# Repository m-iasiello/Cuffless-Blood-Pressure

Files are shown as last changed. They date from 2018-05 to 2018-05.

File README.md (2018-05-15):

# Cuffless-Blood-Pressure
Cuffless Blood Pressure monitor using custom PCB developed from AD8232 HRM and Si1143 pulse ox.  Includes several .ino, pcb schems, and solidworks builds.

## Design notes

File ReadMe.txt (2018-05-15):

This folder contains the relevant schematic and files for the Spring 2018 Cuffless Blood Pressure Measurement Project

Contents:

	Powerpoints
		- Tutorial Presentation: Background information and initial project proposal
		- Update Presentations: Updates on progress through the semester
		- Final Presentation: Overall presentation of the project, work, and results

	Schematic and PCB Layout
		- CufflessPTT-v3.sch: The Eagle schematic for the PTT Measurement PCB 
		- CufflessPTT-v3.brd: The Eagle layout for the PTT Measurement PCB

	Software
		- PTT-BP.ino: The main Arduino code file for BP measurement.  
		- QRS_detection.ino: QRS detection algorithm for R wave detection
		- Si1143_pulse_demo.ino: Driver software for the Si1143, as well as helper functions for identification of the PPG signals
		- CUFFLESS.apk: Installer file for the Cuffless Android app.

	Solidworks Files
		- CAD files for the Cuffless case, as well as the locking pin to hold the case together.

Instructions for use:
	
	1. Install the Android app on an Android phone. 
	2. Press the button on the side to turn on the device. The LEDs should come on.
	3. Pair the Android app with the device by opening the app, and then find and pair to the device named HC-06.
	4. Press the start measurement button.
	5. Hold the electrode side of the device against the inside of your wrist. 
	6. Hold one finger of your opposite firmly on the electrdoe on top, and another finger firmly across the LEDs and photodiode.
	7. The device should display measurements as they are acquired.

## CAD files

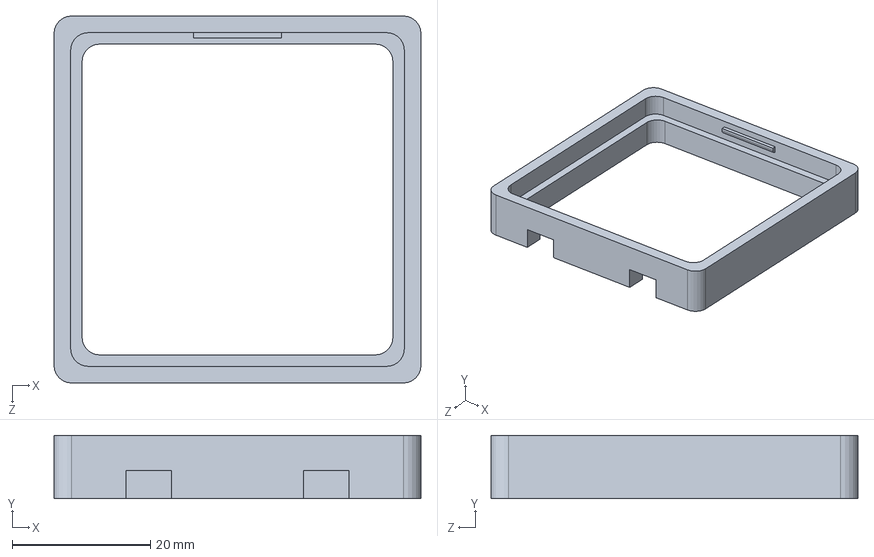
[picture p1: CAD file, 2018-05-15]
Emergency Extender (Uncompleted).SLDPRT
53.1 x 9.14 x 53.1 mm

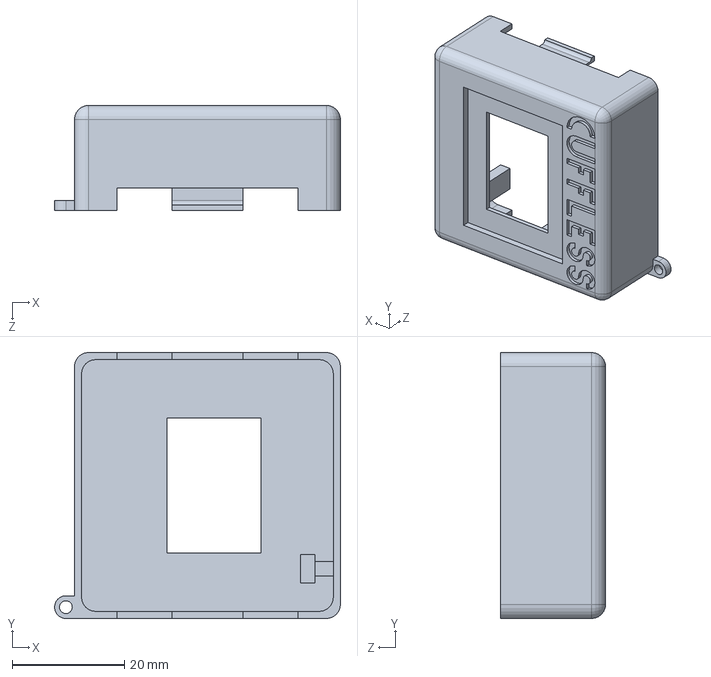
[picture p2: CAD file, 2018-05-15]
Top_V11.SLDPRT
51.1 x 47.5 x 18.8 mm

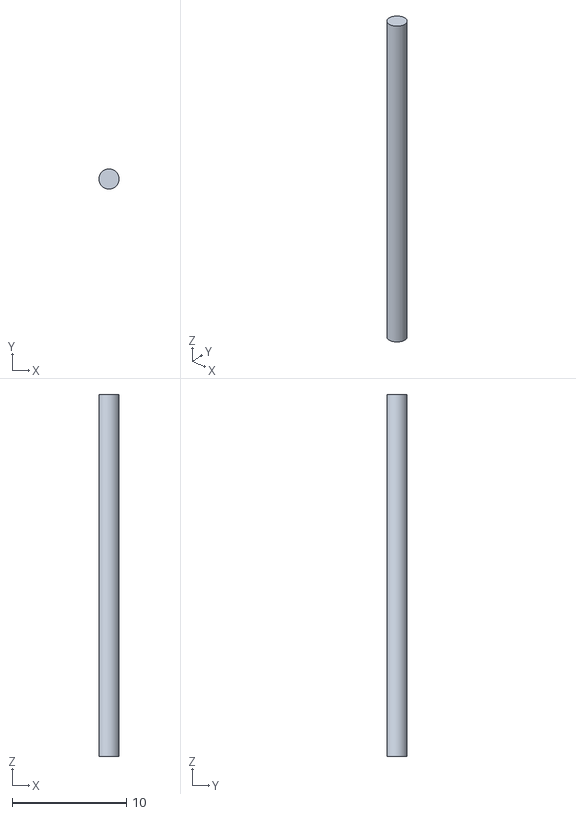
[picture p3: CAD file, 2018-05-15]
Pin.STL
1.78 x 1.78 x 31.8

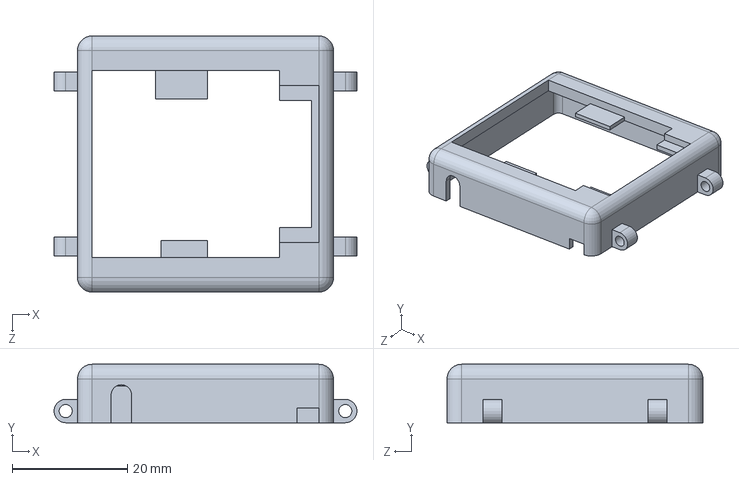
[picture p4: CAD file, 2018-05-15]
Bottom_V8.SLDPRT
52.6 x 10.2 x 44.5 mm

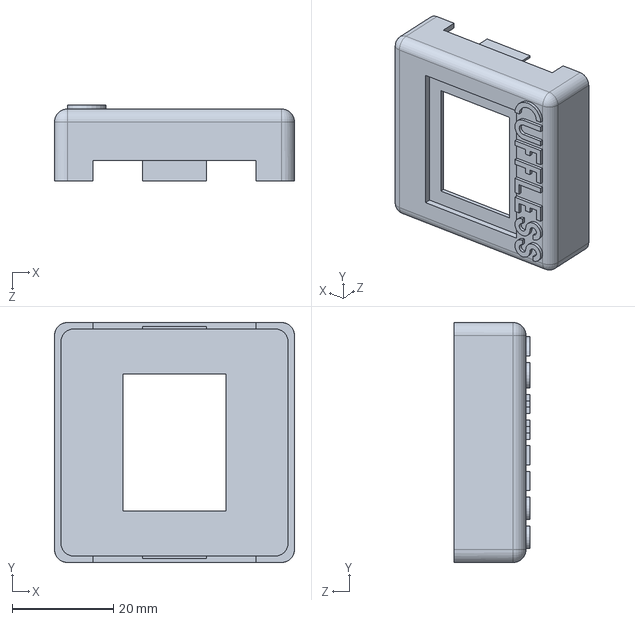
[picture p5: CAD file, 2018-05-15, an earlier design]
Top_V9.SLDPRT
47.5 x 47.5 x 15.0 mm

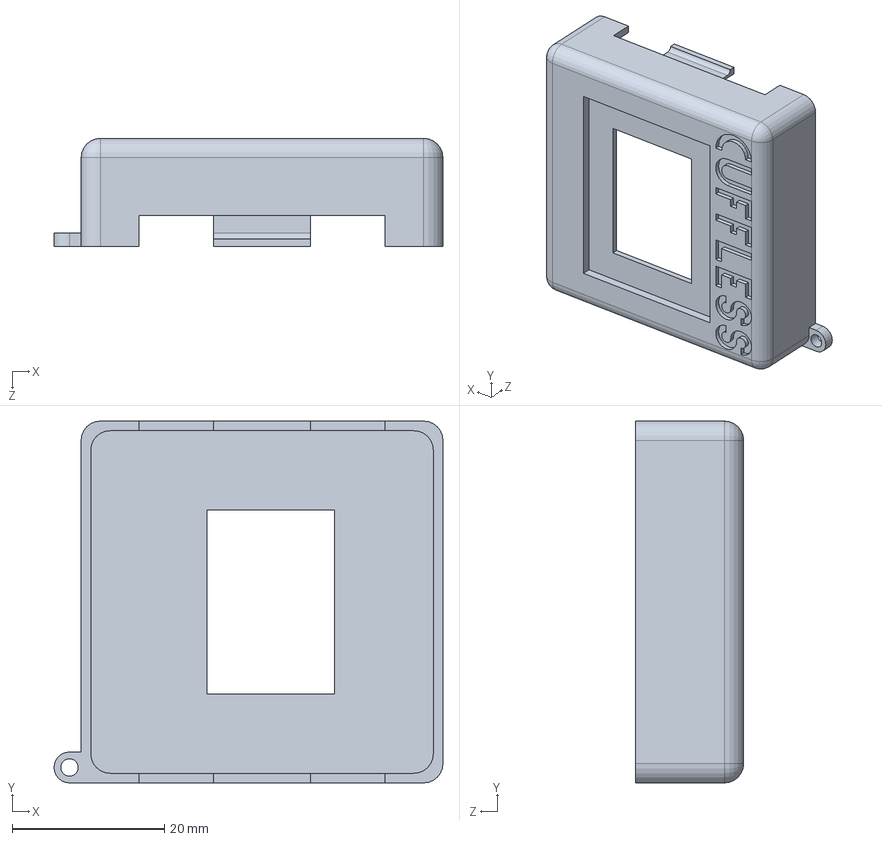
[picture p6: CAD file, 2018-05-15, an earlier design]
Top_V10.SLDPRT
51.1 x 47.5 x 14.2 mm

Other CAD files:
UM2_Top_V11.3mf
Top_V8.SLDPRT
Bottom_V8.STL
Top_V10.STL
Top_V11.STL
Top_V11_Drawing.SLDDRW
Top_V8.STL
Top_V9.STL

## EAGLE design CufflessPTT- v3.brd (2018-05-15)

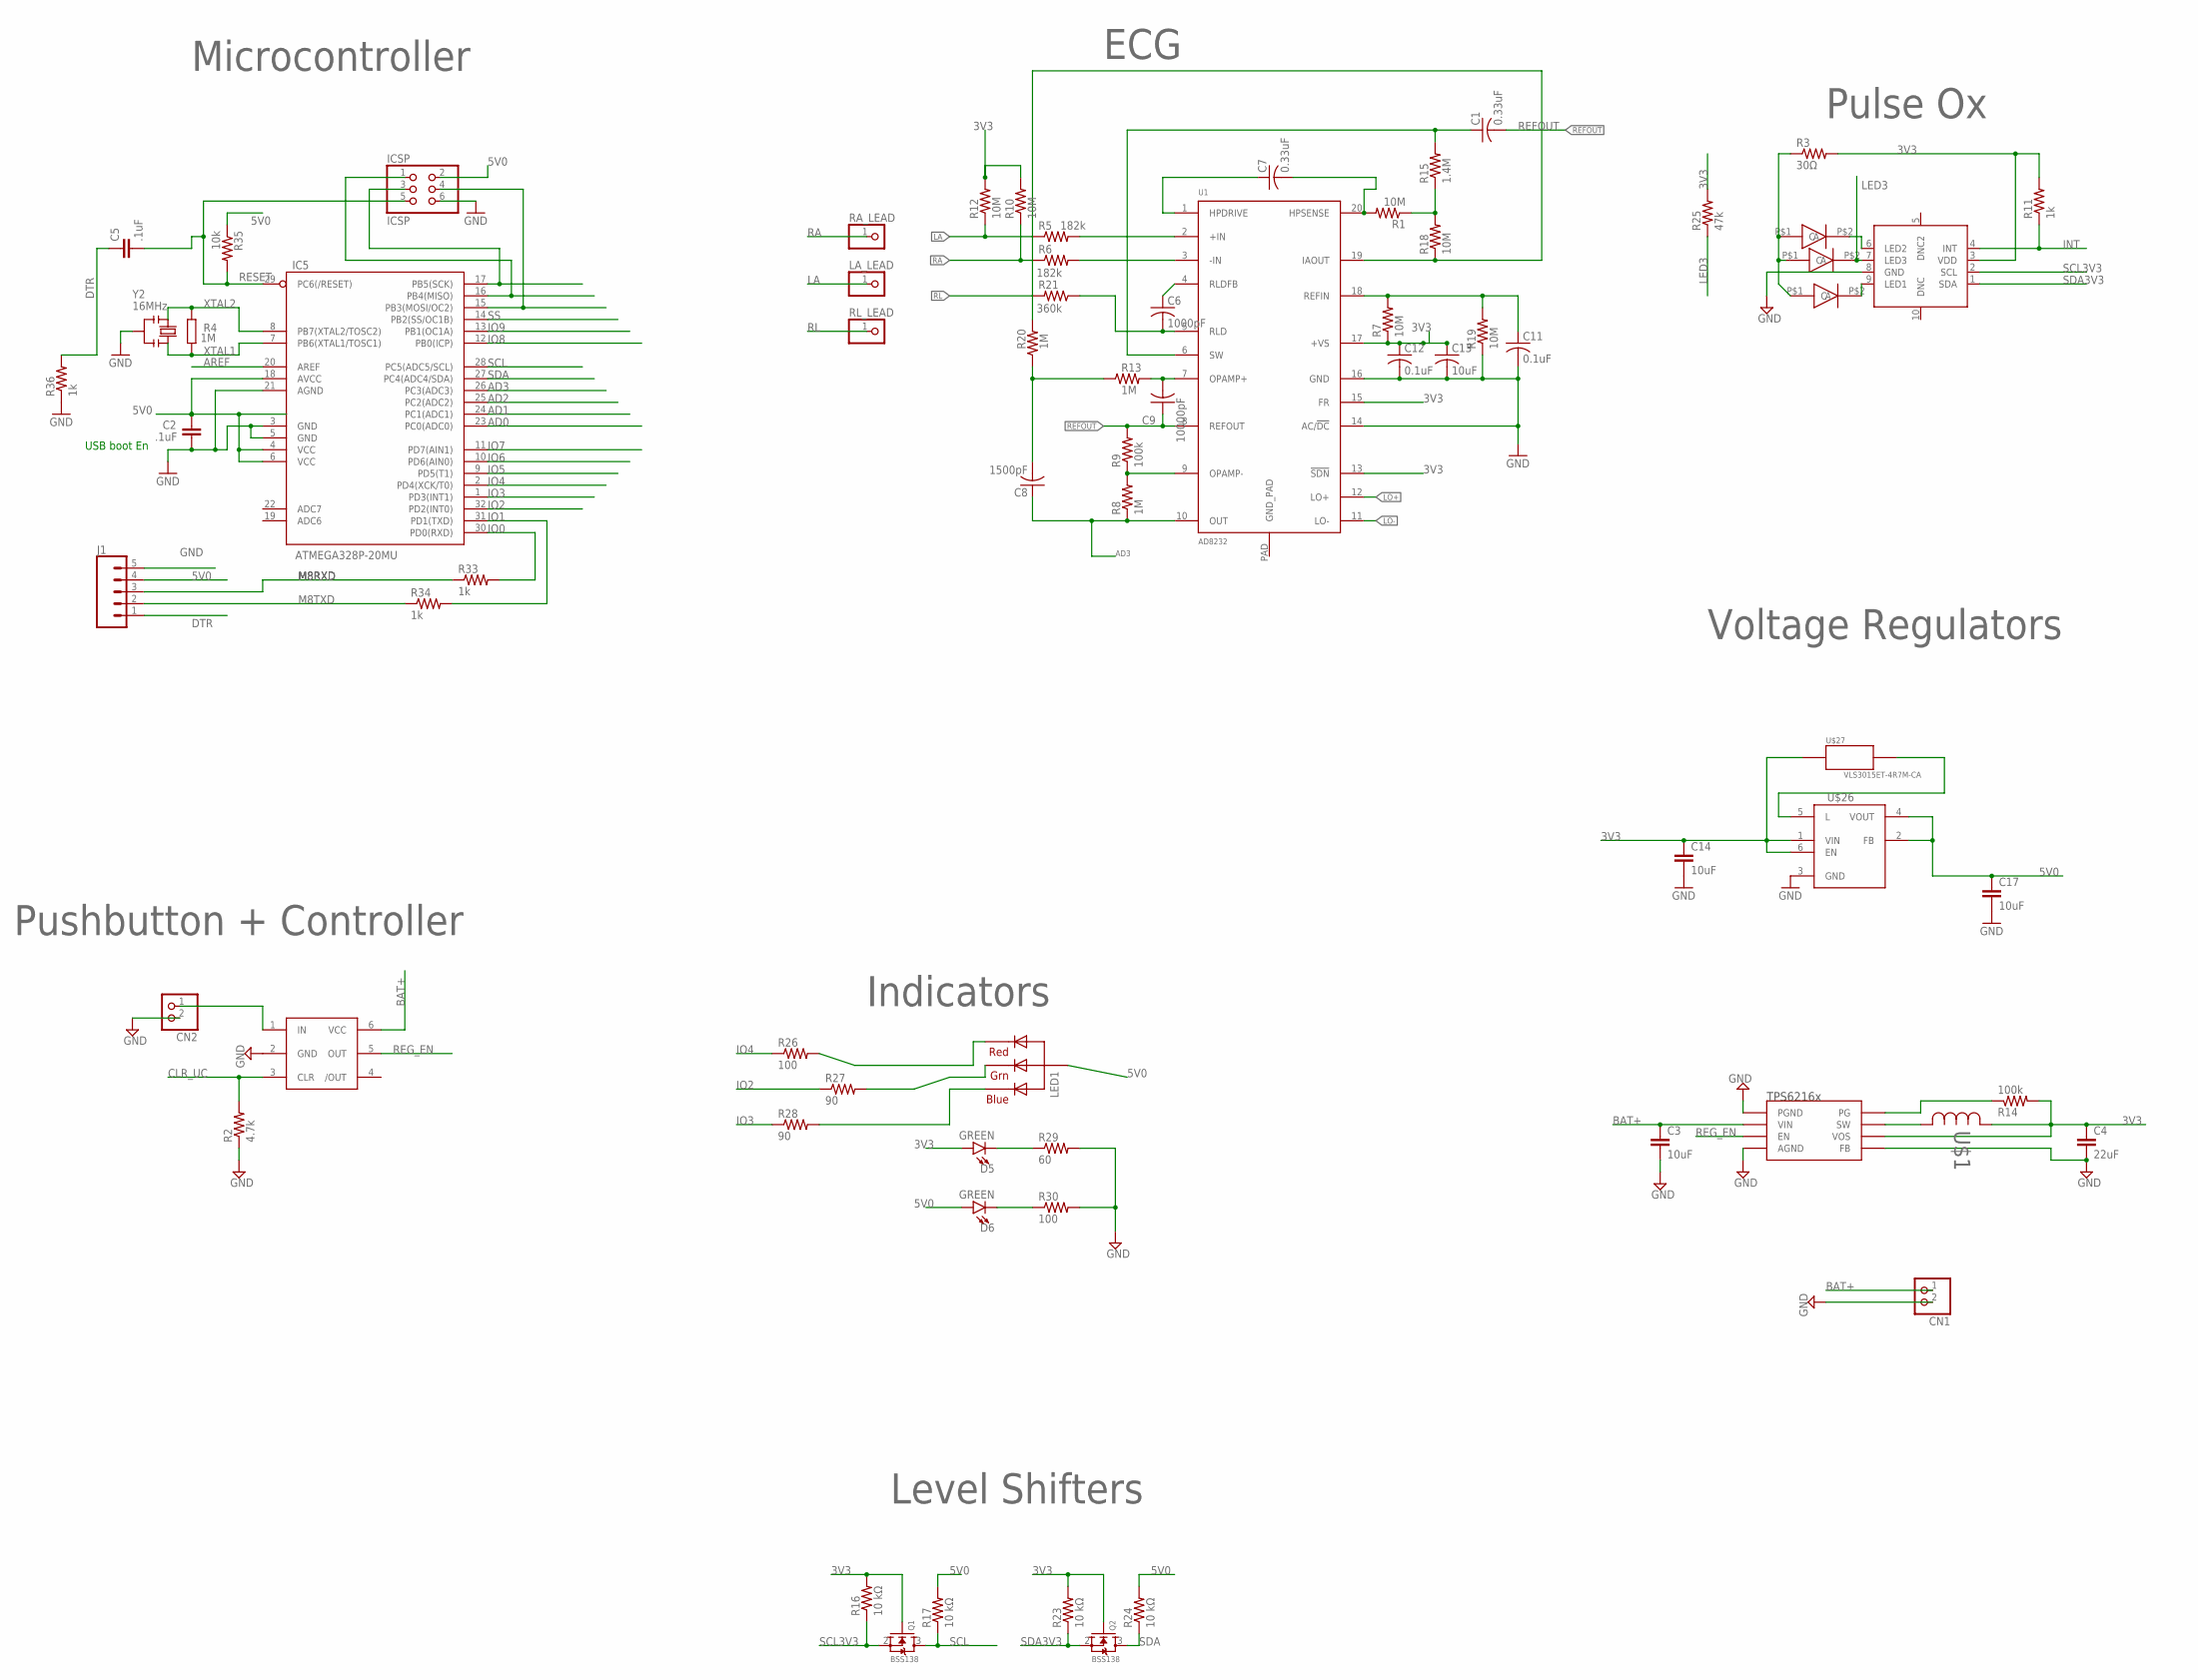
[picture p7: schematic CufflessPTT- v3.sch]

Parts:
C1, C7: 0.33uF; C0603
C2, C5: .1uF; C0603-ROUND
C3, C14, C17: 10uF; C0603; MPN MCNP16V105M5X11
C4: 22uF; C0805
C6: 1000pF; C0603
C8: 1500pF; C0603
C9: 10000pF; C0603
C11, C12: 0.1uF; C0603
C13: 10uF; C0603
CN1, CN2: JST_2PIN-THM; JST-PH-2-THM
D5, D6: GREEN; LED-0603
IC5: ATMEGA328P-20MU; MLF32
ICSP: ICSP; 2X03
J1: CONN_05; 1X05
LA_LEAD: PINHD-1X1; 1X01
LED1: RGBLED_CA-5MM; LED5MMRGB
LED2, LED3, LED4: SMD_COMBO
Q1, Q2: BSS138; SOT23-3
R1, R7, R10, R12, R18, R19: 10M; 0603-RES
R2: 4.7k; R0402
R3: 30Ω; R0402
R4: 1M; R0603-ROUND
R5, R6: 182k; 0603-RES
R8, R13, R20: 1M; 0603-RES
R9: 100k; 0603-RES
R11, R33, R34, R36: 1k; R0402
R14: 100k; R0402
R15: 1.4M; 0603-RES
R16, R17, R23, R24: 10 kΩ; R0402
R21: 360k; 0603-RES
R25: 47k; R0402
R26, R30: 100; R0402
R27, R28: 90; R0402
R29: 60; R0402
R35: 10k; R0402
RA_LEAD: PINHD-1X1; 1X01
RL_LEAD: PINHD-1X1; 1X01
U1: AD8232; LFCSP_20
U$1: VLF3012ST-2R2M1R4; IND_3010
U$4: SI1143; QFN-10
U$5: TPS6216X; 8WSON
U$15: MAX16054; TSOT23-6
U$26: TPS61222; SOT363_6SOIC
U$27: VLS3015ET-4R7M-CA
Y2: 16MHz; RESONATOR

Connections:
3V3: C4.1, C12.1, C13.1, C14.1, D5.A, Q1.1 (G), Q2.1 (G), R3.2, R7.1, R10.2, R11.2, R12.2, R14.2, R16.2, R23.2, R25.2, U1.13 (!SDN), U1.15 (FR), U1.17 (+VS), U$1.1, U$4.3 (VDD), U$5.P$6 (VOS), U$26.1 (VIN), U$26.6 (EN), U$27.1
5V0: C2.2, C17.1, D6.A, IC5.4 (VCC), IC5.6 (VCC), IC5.18 (AVCC), ICSP.2, J1.4, LED1.2 (VCC), R17.2, R24.2, R35.1, U$26.2 (FB), U$26.4 (VOUT)
AD0: IC5.23 (PC0(ADC0))
AD1: IC5.24 (PC1(ADC1))
AD2: IC5.25 (PC2(ADC2))
AD3: C8.1, IC5.26 (PC3(ADC3)), R8.1, U1.10 (OUT)
AREF: IC5.20 (AREF)
BAT+: C3.1, CN1.1 (2), U$5.P$2 (VIN), U$15.6 (VCC)
CLR_UC: R2.2, U$15.3 (CLR)
DTR: C5.1, J1.1, R36.2
GND: C2.1, C3.2, C4.2, C11.2, C12.2, C13.2, C14.2, C17.2, CN1.2 (1), CN2.2 (1), IC5.3 (GND), IC5.5 (GND), IC5.21 (AGND), ICSP.6, J1.5, R2.1, R19.1, R29.2, R30.2, R36.1, U1.14 (AC/!DC), U1.16 (GND), U$4.8 (GND), U$5.P$1 (PGND), U$5.P$4 (AGND), U$5.P$5 (FB), U$5.P$9 (AGND), U$15.2 (GND), U$26.3 (GND), Y2.2
INT: R11.1, U$4.4 (INT)
IO0: IC5.30 (PD0(RXD)), R33.2
IO1: IC5.31 (PD1(TXD)), R34.2
IO2: IC5.32 (PD2(INT0)), R27.1
IO3: IC5.1 (PD3(INT1)), R28.1
IO4: IC5.2 (PD4(XCK/T0)), R26.1
IO5: IC5.9 (PD5(T1))
IO6: IC5.10 (PD6(AIN0))
IO7: IC5.11 (PD7(AIN1))
IO8: IC5.12 (PB0(ICP))
IO9: IC5.13 (PB1(OC1A))
LA: LA_LEAD.1, R5.1, R12.1
LED3: LED2.P$2 (C), R25.1, U$4.7 (LED3)
LO+: U1.12 (LO+)
LO-: U1.11 (LO-)
M8RXD: J1.3, R33.1
M8TXD: J1.2, R34.1
MISO: IC5.16 (PB4(MISO)), ICSP.1
MOSI: IC5.15 (PB3(MOSI/OC2)), ICSP.4
unnamed: R5.2, U1.2 (+IN)
unnamed: CN2.1 (2), U$15.1 (IN)
unnamed: C1.1, R15.2, U1.6 (SW)
unnamed: R1.1, R15.1, R18.2
unnamed: C8.2, R13.1, R20.1
unnamed: R14.1, U$5.P$8 (PG)
unnamed: R6.2, U1.3 (-IN)
unnamed: C9.2, R13.2, U1.7 (OPAMP+)
unnamed: D5.C, R29.1
unnamed: C7.2, R1.2, U1.20 (HPSENSE)
unnamed: C11.1, R7.2, R19.2, U1.18 (REFIN)
unnamed: U$1.2, U$5.P$7 (SW)
unnamed: R8.2, R9.1, U1.9 (OPAMP-)
unnamed: C7.1, U1.1 (HPDRIVE)
unnamed: C6.1, U1.4 (RLDFB)
unnamed: D6.C, R30.1
unnamed: R18.1, R20.2, U1.19 (IAOUT)
unnamed: C6.2, R21.1, U1.5 (RLD)
unnamed: LED2.P$1 (A), LED3.P$1 (A), LED4.P$1 (A), R3.1
unnamed: U$26.5 (L), U$27.2
unnamed: LED3.P$2 (C), U$4.6 (LED2)
unnamed: LED1.4 (BLUE), R28.2
unnamed: LED1.3 (GREEN), R27.2
unnamed: LED1.1 (RED), R26.2
unnamed: LED4.P$2 (C), U$4.9 (LED1)
RA: R6.1, R10.1, RA_LEAD.1
REFOUT: C1.2, C9.1, R9.2, U1.8 (REFOUT)
REG_EN: U$5.P$3 (EN), U$15.5 (OUT)
RESET: C5.2, IC5.29 (PC6(/RESET)), ICSP.5, R35.2
RL: R21.2, RL_LEAD.1
SCK: IC5.17 (PB5(SCK)), ICSP.3
SCL: IC5.28 (PC5(ADC5/SCL)), Q1.3 (D), R17.1
SCL3V3: Q1.2 (S), R16.1, U$4.2 (SCL)
SDA: IC5.27 (PC4(ADC4/SDA)), Q2.3 (D), R24.1
SDA3V3: Q2.2 (S), R23.1, U$4.1 (SDA)
SS: IC5.14 (PB2(SS/OC1B))
XTAL1: IC5.7 (PB6(XTAL1/TOSC1)), R4.1, Y2.3
XTAL2: IC5.8 (PB7(XTAL2/TOSC2)), R4.2, Y2.1

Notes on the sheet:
Voltage Regulators
Pulse Ox
Pushbutton + Controller
ECG
USB boot En
Indicators
Microcontroller
Level Shifters

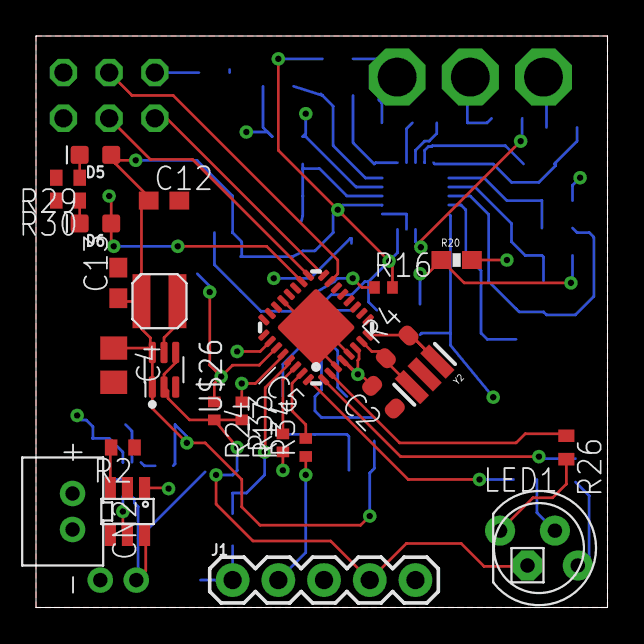
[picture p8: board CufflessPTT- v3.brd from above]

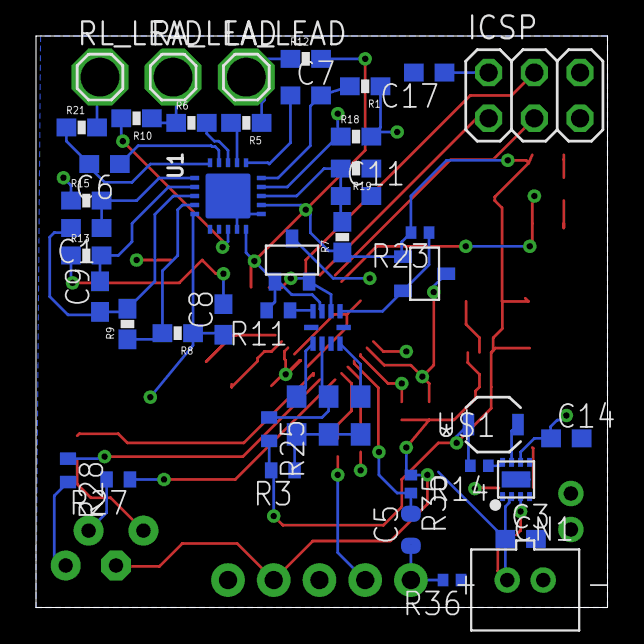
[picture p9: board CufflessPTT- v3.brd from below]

Board: 4 copper layers, 31.8 x 31.8 mm, 71 parts (46 on the bottom side), 56 nets.

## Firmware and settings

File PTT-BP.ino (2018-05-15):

// PTT calculation program using Sparkfun AD8232 HRM and SI1143 PPG sensor.  BME 525
// Includes:
/* SI114_Pulse_Demo.ino
 * demo code for the Modern Device SI1143-based pulse sensor
 * http://moderndevice.com/product/pulse-heartbeat-sensor-pulse-sensor-1x/
 * Paul Badger 2013 with plenty of coding help from Jean-Claude Wippler
 * Hardware setup - please read the chart below and set the appropriate options
 */
// Michael Iasiello

#include <stdio.h>
#include <stdlib.h>
#include <SI114.h> 
const int SAMPLES_TO_AVERAGE = 5;             // samples for smoothing 1 to 10 seem useful 5 is default
// increase for smoother waveform (with less resolution - slower!) 


 //#define SEND_TOTAL_TO_PROCESSING   // Use this option exclusive of other options
                                      // for sending data to HeartbeatGraph in Processing
// #define POWERLINE_SAMPLING         // samples on an integral of a power line period [eg 1/60 sec]
// #define AMBIENT_LIGHT_SAMPLING     // also samples ambient slight (slightly slower)
// #define PRINT_LED_VALS             // print LED raw values
 #define GET_PULSE_READING          // prints HB and signal size


int binOut;     // 1 or 0 depending on state of heartbeat
int BPM;
unsigned long red;        // read value from visible red LED
unsigned long IR1;        // read value from infrared LED1
unsigned long IR2;       // read value from infrared LED2
unsigned long total;     // all three LED reads added together
int signalSize;          // the heartbeat signal minus the offset
const int portForSI114 = 0;
PortI2C myBus (portForSI114);
PulsePlug pulse (myBus); 





// variables for lowpass (moving average) filter
int sensorValue;
float EMA_a_l = 0.4;      //initialization of EMA alpha
float lowpass = 0;          //initialization of EMA S

//variables for highpass (Exp moving average) filter
float EMA_a = 0.026177; //alpha for EMA eq., cuttoff = 3Hz
float EMA_s = 0;            //initialize EMA s
float highpass = 0;
float sensorVal = 0.0;

float threshold = 90;  

//variables for peak detection
float next_ecg_pt = 0;
float ECG_bpm = 0;
float prev_ecg_pt = 0;
float ECG_time_buff = 0;
unsigned long ECG_max_time;
//static unsigned long lastPeakTime;
boolean QRS_detected = false;
boolean get_ready = false;
unsigned long R_peak = 0;


const int LED_PIN =   13;      // the number of the LED pin (digital)

const int ECG_PIN =   A3;       // the number of the ECG pin (analog)
const int PWM_PIN =   1;       // the number of the PWM pin (analog)

const int GREEN = 2;
const int BLUE = 4;
const int RED = 3;

// timing variables
unsigned long foundTimeMillis = 0;        // time at which last QRS was found
unsigned long old_foundTimeMillis = 0;        // time at which QRS before last was found


// PTT and BP variables
int i =0;
int j=0;
int k =0;
float PTT_avg=0;
float PTT_sum = 0;
float lastBP = 0;
float bpm_ecg;
float BP_total =0;
float BP_avg=0;
float BP_val=0;
int counter=0;
unsigned long ECG_peak_time;
static unsigned long PPG_peak_time;
boolean check_ppg = false;
int PTT_val;
float bpm = 0;
float lastBP_val = 0;

// Variable timers
unsigned long currentTime = 0;
unsigned long lastTime = 0;
unsigned long lastOutputTime;

int incomingByte = 0;

void setup() {
  // initialize the serial communication:

    if (pulse.isPresent()) {
        Serial.print("PPG Sensor Found");
        Serial.println(portForSI114);
    }
        else{
        Serial.print("PPG Sensor not found.");
        Serial.println(portForSI114);
    }
    Serial.begin(9600);
    
    Serial.println("\n Welcome To to the Cuffless BP Monitor!");
    Serial.println("Place device on inside of wrist. Place opposite fingers on top electrode and LEDs");
    
    digitalWrite(3, HIGH);

      // set the digital pin as output:
  pinMode(LED_PIN, OUTPUT);
  pinMode(7, OUTPUT);
  pinMode(ECG_PIN, INPUT);

  pinMode(GREEN, OUTPUT);
  pinMode(BLUE, OUTPUT);
  pinMode(RED, OUTPUT);


  // set LED to off
  digitalWrite(LED_PIN, LOW);

  //Setting LEDS init
  digitalWrite(GREEN, LOW);
  digitalWrite(BLUE, LOW);
  digitalWrite(RED, HIGH);

  initPulseSensor();


}
  
void loop() {
  
      currentTime = millis();

      // Tell user what is happening based on elapsed time
      if((currentTime - lastTime)>=5000){
        Serial.println(" ...Measurement in progress... ");
        lastTime = currentTime;
        
        if((currentTime - lastOutputTime)>=10000){
          Serial.println(" ...Reposition the device... "); 
        }
      } 


      // Reset microcontroller if LEDs bugged
      // Send '\n" or just enter through serial monitor input (or smartphone app)
      if (Serial.available()>0){
        incomingByte = Serial.read();
        if(incomingByte == 10){
          softReset();
        }
        Serial.println(incomingByte, DEC);
      }

      // Read values for both ECG and PPG
      // ECG value will need to be filtered
      readPulseSensor();        
      sensorValue = analogRead(A3);                

      // **ECG LOWPASS EMA**
      lowpass = (EMA_a_l*sensorValue) + ((1-EMA_a_l)*lowpass);    //run the EMA
           
      // **ECG HIGHPASS EMA**
      EMA_s = (EMA_a*lowpass) + ((1-EMA_a)*EMA_s);
      highpass = lowpass - EMA_s;
      //Serial.println(highpass);


      
      //QRS detection using thresholding
      next_ecg_pt = highpass;

      // Check to see if the next ECG point is greater than a predetermined threshold
      // If it is, mark the time & set a flag
      // If it is not, do not set flag
      if(next_ecg_pt > threshold){
        ECG_max_time = millis();   
        get_ready = true;
      }
      else if(next_ecg_pt <= threshold){
        get_ready = false;
      }

      // If the flag is set, check to see if the ECG is decreasing.
      // This signifies that the R-peak has just occured
      // If true: set another flag, flash LED yellow
      // If false: reset flag, flash red LED
      if(get_ready == true){
          if(next_ecg_pt < prev_ecg_pt){
            get_ready = false;
            foundTimeMillis = ECG_max_time;
            QRS_detected = true;

            //Set Yellow LED ON
              digitalWrite(GREEN, HIGH);
              digitalWrite(BLUE, LOW);
              digitalWrite(RED, HIGH);
          }
          else{
            get_ready = false;
            
            //Set Red LED ON
            digitalWrite(GREEN, LOW);
            digitalWrite(BLUE, LOW);
            digitalWrite(RED, HIGH);

          }
        }

      prev_ecg_pt = next_ecg_pt;

      // Check to see if the QRS detection has occured on succesive heartbeats
      // This is important for calculating HR.
      // If true: set new flags, calculate HR, store QRS time, flash LED blue
      // IF false: reset flags
      if (QRS_detected == true && (foundTimeMillis - old_foundTimeMillis)< 2000 && (foundTimeMillis - old_foundTimeMillis)> 700){
        
        QRS_detected = false;
        ECG_bpm = 60000/(foundTimeMillis - old_foundTimeMillis);
        
        ECG_peak_time = old_foundTimeMillis;
        check_ppg = true;

        //Set Blue LED ON
        digitalWrite(GREEN, LOW);
        digitalWrite(BLUE, HIGH);
        digitalWrite(RED, LOW);

        Serial.println("ECG signal acquired.");
      }
      else{
        QRS_detected = false;
        check_ppg = false;
      }
      old_foundTimeMillis = foundTimeMillis;

      
      // If the flag is set, we need to check the PTT value and see if it is in an appropriate ra
      if(check_ppg == true){
          check_ppg = false;
          PTT_val = PPG_peak_time - ECG_peak_time;

          // Set green LED ON
          digitalWrite(GREEN, LOW);
          digitalWrite(BLUE, HIGH);
          digitalWrite(RED, LOW);
          
         if(PTT_val < 600 && PTT_val>25){
              //Serial.print(PTT_val);
              //Serial.print();
              if(PTT_val>500){
                PTT_val = PTT_val/6;
              }
              else if(PTT_val>400){
                PTT_val = PTT_val/5;
              }
              else if(PTT_val>300){
                PTT_val = PTT_val/4;
              }
              else if(PTT_val>200){
                  PTT_val = PTT_val/3;
              }
              else if(PTT_val<50){
                PTT_val=PTT_val*4;
              }
              else if(PTT_val<20){
                PTT_val=PTT_val*5;
              }
              
              
              
              //Serial.print(PTT_val);


              bpm = (ECG_bpm + BPM)/2;
              
              lastBP_val = BP_val;
              BP_val = (-0.6881*PTT_val) + 210.94; 
              BP_val = BP_val*0.85;
              BP_total = BP_avg*counter + BP_val;
              counter++;
              BP_avg = BP_total/counter;
              
              Serial.print("BP measurement found (");
              Serial.print(counter);
              Serial.print("/5): ");
              Serial.println(BP_avg);
              //Serial.print("Your HR is"); 
              //Serial.print(" ");
             // Serial.print(ECG_bpm);
              //Serial.print(" beats per minute. ");

              // Start counting in between output times
              // If the time is greater than some threshold,
              // instruct the user to reposition finger
              lastOutputTime = currentTime;

             if(counter ==5){
                //Set Purple LED ON
                digitalWrite(GREEN, HIGH);
                digitalWrite(BLUE, LOW);
                digitalWrite(RED, LOW);

                //leave green light on for 1 second
                delay(1000);
                

                Serial.println("BP measurement found (5/5).");

                Serial.println("Your Systolic BP is estimated to be ");
                Serial.print(BP_avg);
                Serial.print(" mmHg. ");
                Serial.println("Continue to measure again. ");

                
                counter = 0;
                BP_avg = 0;
                BP_total - 0;
              }        
          }
          else{
              check_ppg = false;
              QRS_detected = false;
              get_ready = false;     
          }
      }
      
}
      

// simple smoothing function for  heartbeat detection and processing
float smooth(float data, float filterVal, float smoothedVal){

    if (filterVal > 1){      // check to make sure param's are within range
        filterVal = .99;
    }
    else if (filterVal <= 0.0){
        filterVal = 0.01;
    }

    smoothedVal = (data * (1.0 - filterVal)) + (smoothedVal  *  filterVal);
    return smoothedVal;
    
}

void softReset(){
  asm volatile (" jmp 0");
}

void initPulseSensor(){
    
    pulse.setReg(PulsePlug::HW_KEY, 0x17);  
    // pulse.setReg(PulsePlug::COMMAND, PulsePlug::RESET_Cmd);

   
    pulse.setReg(PulsePlug::INT_CFG, 0x03);       // turn on interrupts
    pulse.setReg(PulsePlug::IRQ_ENABLE, 0x10);    // turn on interrupt on PS3
    pulse.setReg(PulsePlug::IRQ_MODE2, 0x01);     // interrupt on ps3 measurement
    pulse.setReg(PulsePlug::MEAS_RATE, 0x84);     // see datasheet
    pulse.setReg(PulsePlug::ALS_RATE, 0x08);      // see datasheet
    pulse.setReg(PulsePlug::PS_RATE, 0x08);       // see datasheet

    // Current setting for LEDs pulsed while taking readings
    // PS_LED21  Setting for LEDs 1 & 2. LED 2 is high nibble
    // each LED has 16 possible (0-F in hex) possible settings
    // read the 
    pulse.setReg(PulsePlug::PS_LED21, 0xFF);      // LED current for 2 (IR1 - high nibble) & LEDs 1 (red - low nibble) 
    pulse.setReg(PulsePlug::PS_LED3, 0x0F);       // LED current for LED 3 (IR2)

   

    pulse.writeParam(PulsePlug::PARAM_CH_LIST, 0x77);         // all measurements on

    // increasing PARAM_PS_ADC_GAIN will increase the LED on time and ADC window
    // you will see increase in brightness of visible LED's, ADC output, & noise 
    // datasheet warns not to go beyond 4 because chip or LEDs may be damaged
    pulse.writeParam(PulsePlug::PARAM_PS_ADC_GAIN, 0x04);


    // You can select which LEDs are energized for each reading.
    // The settings below turn on only the LED that "normally" would be read
    // ie LED1 is pulsed and read first, then LED2 is pulsed and read etc.
    pulse.writeParam(PulsePlug::PARAM_PSLED12_SELECT, 0x21);  // 21 = LED 2 & LED 1 (red) resp.                                                              
    pulse.writeParam(PulsePlug::PARAM_PSLED3_SELECT, 0x04);   // 4 = LED 3 only

    // Sensors for reading the three LEDs
    // 0x03: Large IR Photodiode
    // 0x02: Visible Photodiode - cannot be read with LEDs on - just for ambient measurement
    // 0x00: Small IR Photodiode
    pulse.writeParam(PulsePlug::PARAM_PS1_ADCMUX, 0x02);      // PS1 photodiode select 
    pulse.writeParam(PulsePlug::PARAM_PS2_ADCMUX, 0x02);      // PS2 photodiode select 
    pulse.writeParam(PulsePlug::PARAM_PS3_ADCMUX, 0x02);      // PS3 photodiode select  

    pulse.writeParam(PulsePlug::PARAM_PS_ADC_COUNTER, B01110000);    // B01110000 is default                                   
    pulse.setReg(PulsePlug::COMMAND, PulsePlug::PSALS_AUTO_Cmd);     // starts an autonomous read loop
    // Serial.println(pulse.getReg(PulsePlug::CHIP_STAT), HEX);  
}

void readPulseSensor(){

    static int foundNewFinger;
    static  int valley=0, peak=0, smoothPeak, smoothValley, binOut, lastBinOut, BPM;
    static unsigned long lastTotal, lastMillis,  valleyTime = millis(), lastValleyTime = millis(), peakTime = millis(), lastPeakTime=millis(), lastBeat, beat;
    static float baseline, HFoutput, HFoutput2, shiftedOutput, LFoutput, hysterisis;
    

    
    unsigned long total=0, start;
    int i=0;
    int signalSize;
    red = 0;
    IR1 = 0;
    IR2 = 0;
    total = 0;
    start = millis();
         
    
     #ifdef POWERLINE_SAMPLING
     
     while (millis() - start < 16){   // 60 hz - or use 33 for two cycles
     // 50 hz in Europe use 20, or 40
       Serial.print("sample");
     #else     
     while (i < SAMPLES_TO_AVERAGE){      
     #endif
     
     
     #ifdef AMBIENT_LIGHT_SAMPLING   
     pulse.fetchData();
     
     #else 
     pulse.fetchLedData();
     #endif
     
     red += pulse.ps1;
     IR1 += pulse.ps2;
     IR2 += pulse.ps3;
     i++;
     }
     
    red = red / i;  // get averages
    IR1 = IR1 / i;
    IR2 = IR2 / i;
    total = red + IR1 + IR2;
    
   

//#ifdef AMBIENT_LIGHT_SAMPLING
//
//    Serial.print(pulse.resp, HEX);     // resp
//    Serial.print("\t");
//    Serial.print(pulse.als_vis);       //  ambient visible
//    Serial.print("\t");
//    Serial.print(pulse.als_ir);        //  ambient IR
//    Serial.print("\t");
//
//#endif

//
//#ifdef PRINT_LED_VALS
//
//    Serial.print(red);
//    Serial.print("\t");
//    Serial.print(IR1);
//    Serial.print("\t");
//    Serial.print(IR2);
//    Serial.print("\t");
//    Serial.println((long)total);   
//
//#endif

 #ifdef SEND_TOTAL_TO_PROCESSING
    //Serial.println(total);
 #endif

 #ifdef GET_PULSE_READING

    // except this one for Processing heartbeat monitor
    // comment out all the bottom print lines

    if (lastTotal < 20000L && total > 20000L) foundNewFinger = 1;  // found new finger!

    lastTotal = total;
     
    // if found a new finger prime filters first 20 times through the loop
    if (++foundNewFinger > 25) foundNewFinger = 25;   // prevent rollover 

    if ( foundNewFinger < 20){
        baseline = total - 200;   // take a guess at the baseline to prime smooth filter
   //Serial.println("......");     
    }
    
    else if(total > 20000L) {    // main running function
    
    
        // baseline is the moving average of the signal - the middle of the waveform
        // the idea here is to keep track of a high frequency signal, HFoutput and a 
        // low frequency signal, LFoutput
        // The HF signal is shifted downward slightly (heartbeats are negative peaks)
        // The high freq signal has some hysterisis added. When the HF signal is less than the 
        // shifted LF signal, we have found a heartbeat.
        baseline = smooth(total, 0.99, baseline);   // 
        HFoutput = smooth((total - baseline), 0.2, HFoutput);    // recycling output - filter to slow down response
        HFoutput2 = HFoutput + hysterisis;     
        LFoutput = smooth((total - baseline), 0.95, LFoutput);
        // heartbeat signal is inverted - we are looking for negative peaks
        shiftedOutput = LFoutput - (signalSize * .05);

        // We need to be able to keep track of peaks and valleys to scale the output for 
        // user convenience. Hysterisis is also scaled.
        if (HFoutput  > peak) peak = HFoutput; 
        if (peak > 1500) peak = 1500; 
        //Serial.println(shiftedOutput);
        //Serial.println("\t");
        if (millis() - lastPeakTime > 1800){  // reset peak detector slower than lowest human HB
            smoothPeak =  smooth((float)peak, 0.6, (float)smoothPeak);  // smooth peaks
            peak = 0;
            lastPeakTime = millis();
            PPG_peak_time = lastPeakTime; 
            //Serial.println("peak if");
        }

        if (HFoutput  < valley)   valley = HFoutput;
        if (valley < -1500) valley = -1500;

        if (millis() - lastValleyTime > 1800){  // reset valleys detector slower than lowest human HB
            smoothValley =  smooth((float)valley, 0.6, (float)smoothValley);  // smooth valleys
            valley = 0;
            lastValleyTime = millis();      
                        //Serial.println("valley if");     
        }

        signalSize = smoothPeak - smoothValley;  // this the size of the smoothed HF heartbeat signal
        
        // Serial.print(" T  ");
         //Serial.println(signalSize); 

        if(HFoutput2 < shiftedOutput){
            lastBinOut = binOut;
            binOut = 1;
         //   Serial.println("\t1");
            hysterisis = - constrain((signalSize / 10), 35, 120) ;   // you might want to divide by smaller number
            // if you start getting "double bumps"
        } 
        else {
         //   Serial.println("\t0");
            lastBinOut = binOut;
            binOut = 0;
            hysterisis = constrain((signalSize / 10), 35, 120);    // ditto above
            
        } 

  if (lastBinOut == 1 && binOut == 0){
      //Serial.println(binOut);
  }

        if (lastBinOut == 0 && binOut == 1){
            lastBeat = beat;
            beat = millis();

            BPM = 60000 / (beat - lastBeat);
            //Serial.print(binOut);
            //Serial.print("\t BPM ");
            //Serial.print(BPM);  
            //Serial.print("\t PPG peak found ");
            //Serial.println(lastPeakTime);
 
        }

    }
 #endif

}

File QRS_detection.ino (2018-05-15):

/* maximum frequency seems to be at about 8 kHz */

#include <stdio.h>
#include <stdlib.h>

#define M 			5
#define N 			30
#define winSize			250 
#define HP_CONSTANT		((float) 1 / (float) M)
#define MAX_BPM  		100

// resolution of RNG
#define RAND_RES 100000000

// constants won't change. Used here to set a pin number 
const int LED_PIN =   13;      // the number of the LED pin (digital)
const int MOTOR_PIN = 12;      // the number of the MOTOR pin (digital)
const int ECG_PIN =   0;       // the number of the ECG pin (analog)
const int PWM_PIN =   1;       // the number of the PWM pin (analog)

// pins for leads off detection
const int LEADS_OFF_PLUS_PIN  = 10;      // the number of the LO+ pin (digital)
const int LEADS_OFF_MINUS_PIN = 11;      // the number of the LO- pin (digital) 

// timing variables
unsigned long previousMicros  = 0;        // will store last time LED was updated
unsigned long foundTimeMicros = 0;        // time at which last QRS was found
unsigned long old_foundTimeMicros = 0;        // time at which QRS before last was found
unsigned long currentMicros   = 0;        // current time

#define LED_ON_TIME_MICROS   200000
#define MOTOR_ON_TIME_MICROS 200000

// interval at which to take samples and iterate algorithm (microseconds)
const long PERIOD = 1000000 / winSize;

// circular buffer for BPM averaging
float bpm = 0;

#define BPM_BUFFER_SIZE 5
unsigned long bpm_buff[BPM_BUFFER_SIZE] = {0};
int bpm_buff_WR_idx = 0;
int bpm_buff_RD_idx = 0;

int tmp = 0;


void setup() {
  // set the digital pin as output:
  pinMode(LED_PIN, OUTPUT);
  pinMode(7, OUTPUT);
  pinMode(MOTOR_PIN, OUTPUT);
  pinMode(ECG_PIN, INPUT);

  // leads for electrodes off detection
  pinMode(LEADS_OFF_PLUS_PIN, INPUT); // Setup for leads off detection LO +
  pinMode(LEADS_OFF_MINUS_PIN, INPUT); // Setup for leads off detection LO -

  // set LED to off
  digitalWrite(LED_PIN, LOW);
  
  Serial.begin(115200);
}

void loop() {        
  currentMicros = micros();

  // iterate if it's time for a new data point (according to PERIOD)
  if (currentMicros - previousMicros >= PERIOD) {
    // save the last time you blinked the LED
    previousMicros = currentMicros;

    // see if it's time to turn LED off    
    if((currentMicros - foundTimeMicros) > LED_ON_TIME_MICROS){
      digitalWrite(LED_PIN, LOW);  
    }
    
    // see if it's time to turn MOTOR off
    if((currentMicros - foundTimeMicros) > MOTOR_ON_TIME_MICROS){
      digitalWrite(MOTOR_PIN, LOW); 
    }
  
    // only read in data and perform detection if leads are on
    boolean QRS_detected = false;
    
    // only read data if ECG chip has detected that leads are attached to patient
    boolean leads_are_on = (digitalRead(LEADS_OFF_PLUS_PIN) == 0) && (digitalRead(LEADS_OFF_MINUS_PIN) == 0);
    
    if(leads_are_on){           
      // read next ECG data point
      int next_ecg_pt = analogRead(ECG_PIN);
      //Serial.println(next_ecg_pt);
      //Serial.print("\t");
      // give next data point to algorithm
      QRS_detected = detect(next_ecg_pt);
    
            
      if(QRS_detected == true){
        foundTimeMicros = micros();
        Serial.println(foundTimeMicros);
        Serial.print("\t");
        // set the LED with the ledState of the variable:
        digitalWrite(LED_PIN, HIGH);

        bpm_buff[bpm_buff_WR_idx] = (60.0 / (((float) (foundTimeMicros - old_foundTimeMicros)) / 1000000.0));
        bpm_buff_WR_idx++;
      	bpm_buff_WR_idx %= BPM_BUFFER_SIZE;

        bpm += bpm_buff[bpm_buff_RD_idx];
		
	      tmp = bpm_buff_RD_idx - BPM_BUFFER_SIZE + 1;
	      if(tmp < 0) tmp += BPM_BUFFER_SIZE;
		
        bpm -= bpm_buff[tmp];
        
        bpm_buff_RD_idx++;
      	bpm_buff_RD_idx %= BPM_BUFFER_SIZE;

        old_foundTimeMicros = foundTimeMicros;

        Serial.println(bpm / ((float) BPM_BUFFER_SIZE - 1));

      }
    }    
  }
}



/* Portion pertaining to Pan-Tompkins QRS detection */


// circular buffer for input ecg signal
// we need to keep a history of M + 1 samples for HP filter
float ecg_buff[M + 1] = {0};
int ecg_buff_WR_idx = 0;
int ecg_buff_RD_idx = 0;

// circular buffer for input ecg signal
// we need to keep a history of N+1 samples for LP filter
float hp_buff[N + 1] = {0};
int hp_buff_WR_idx = 0;
int hp_buff_RD_idx = 0;

// LP filter outputs a single point for every input point
// This goes straight to adaptive filtering for eval
float next_eval_pt = 0;

// running sums for HP and LP filters, values shifted in FILO
float hp_sum = 0;
float lp_sum = 0;

// working variables for adaptive thresholding
float treshold = 0;
boolean triggered = false;
int trig_time = 0;
float win_max = 0;
int win_idx = 0;

// numebr of starting iterations, used determine when moving windows are filled
int number_iter = 0;
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

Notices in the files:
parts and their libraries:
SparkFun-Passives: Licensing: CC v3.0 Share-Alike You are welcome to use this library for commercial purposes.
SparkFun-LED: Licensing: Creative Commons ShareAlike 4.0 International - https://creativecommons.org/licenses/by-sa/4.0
